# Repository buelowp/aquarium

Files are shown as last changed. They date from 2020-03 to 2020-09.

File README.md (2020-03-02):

# Aquarium Sensor Monitor

I have had aquariums for a while, so I decided one day to add some specific sensors to help me keep track of the
health of the aquarium over time. Atlas makes some really nice, if not expensive, water sensors than can be used in both
fresh and saltwater tanks. For my freshwater tank, I plan to add dissolved oxygen and a pH sensor to help me keep track
of what's going on during the day. I also plan to add a temperature monitor and have added support for keeping track 
of the flow rate for the pump and a water level sensor to make sure I have water in there. The goal is to give me 
some insight into tank health as time goes by, and provide me with rapid warning if something critically bad happens.

To do this, I've created a board to hold a Rasperry PI Zero W, along with space to add the Atlas sensors and a ADC to 
help me keep track of water level. It is a somewhat complicated 4 layer PCB that includes the PI, three Atlas sensor installations, two temp probes, a couple of random GPIO (to control whatever), and an 8 channel ADC, though currently 
I only use 1. They don't make a through hole 1 channel ADC that I can find.

This is also designed to work with my Android Things Aquarium display, which will give me some visual feedback when 
wanted about the state of the tank. It will also give me the ability to track cleanings, filter changes, and a list 
of other things that should be tracked over time to avoid letting them go too long.

## Installation

You need a PI zero, with build-essentials and cmake. You compile it doing the following

```
mkdir build
cd build
cmake ..
make
cp app/aquarium /usr/bin
```

You must copy the aquarium.config file to /root/.config, as this app MUST run as root. It's easiest if you start 
it from rc.local as the last item in the list. It has a function to wait on the network, so that shouldn't be too 
big a problem. If the MQTT server doesn't come up in 5 minutes, it will fail. The whole point of this is MQTT 
access to data. It also can talk to AdafruitIO, but doesn't block waiting for that. If that doesn't connect, then 
you can't talk to AdafruitIO.

I won't got into detail about how to build out the hardware right now.

## Configuration

I will describe how to populate the config file here soon.

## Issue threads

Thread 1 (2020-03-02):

Create an error if a device suddenly goes away

buelowp, 2020-03-02:
This app should notice if a device stops reporting and flag that as an error.

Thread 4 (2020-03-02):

convert MQTT to Paho

buelowp, 2020-03-02:
The current mosquitto lib has been deprecated and may not work forever. Switch to Paho C++ for the MQTT implementation.

buelowp, 2020-03-12:
Merged phao port, got it working.

Closed 2020-03-12.

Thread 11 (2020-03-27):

Temp probe names are broken

buelowp, 2020-03-27:
Names assigned to temp probes are not working correctly again. Need to fix this.

buelowp, 2020-03-27:
Merged

Closed 2020-03-27.

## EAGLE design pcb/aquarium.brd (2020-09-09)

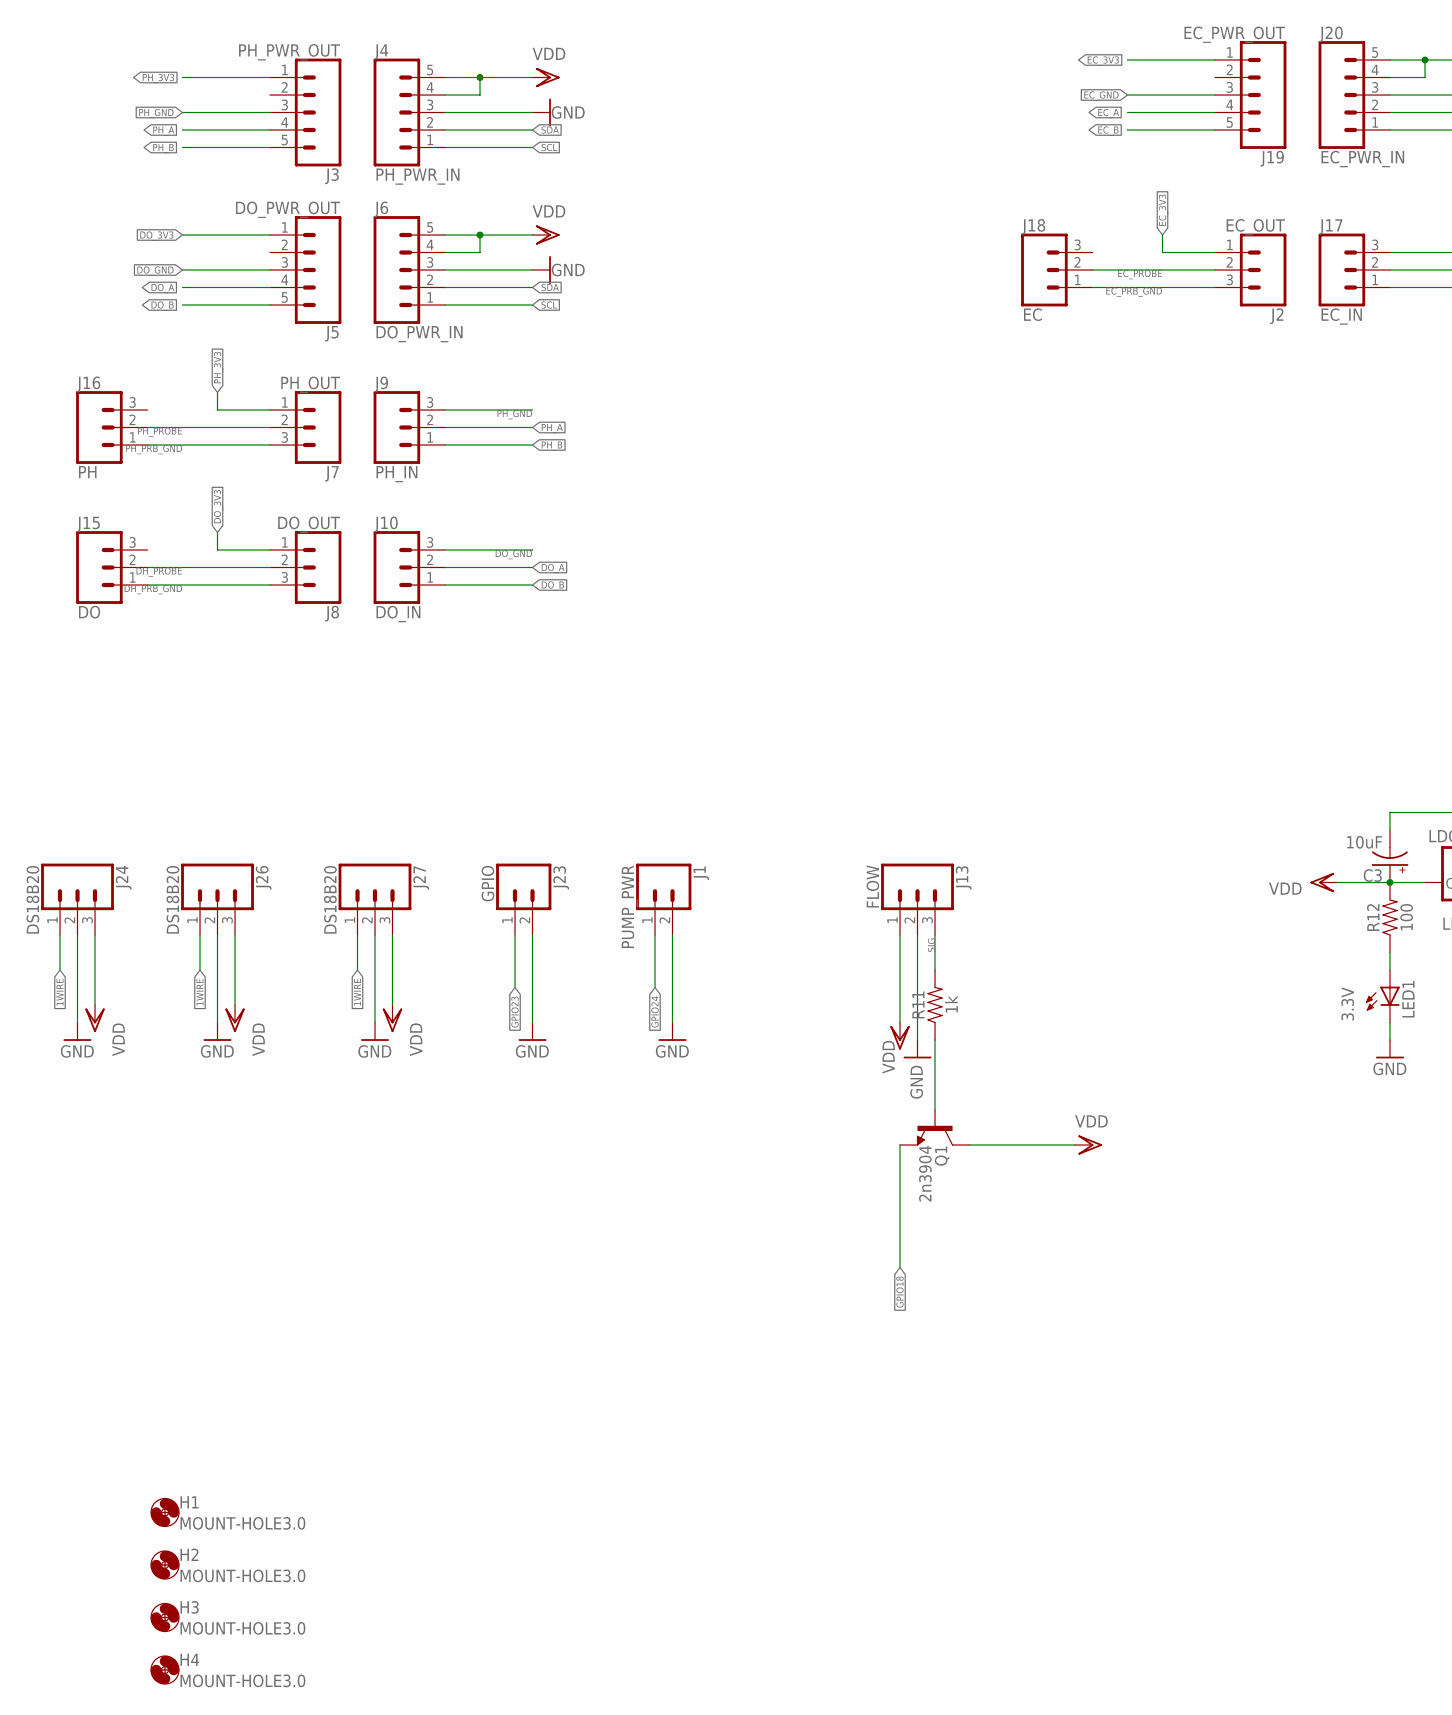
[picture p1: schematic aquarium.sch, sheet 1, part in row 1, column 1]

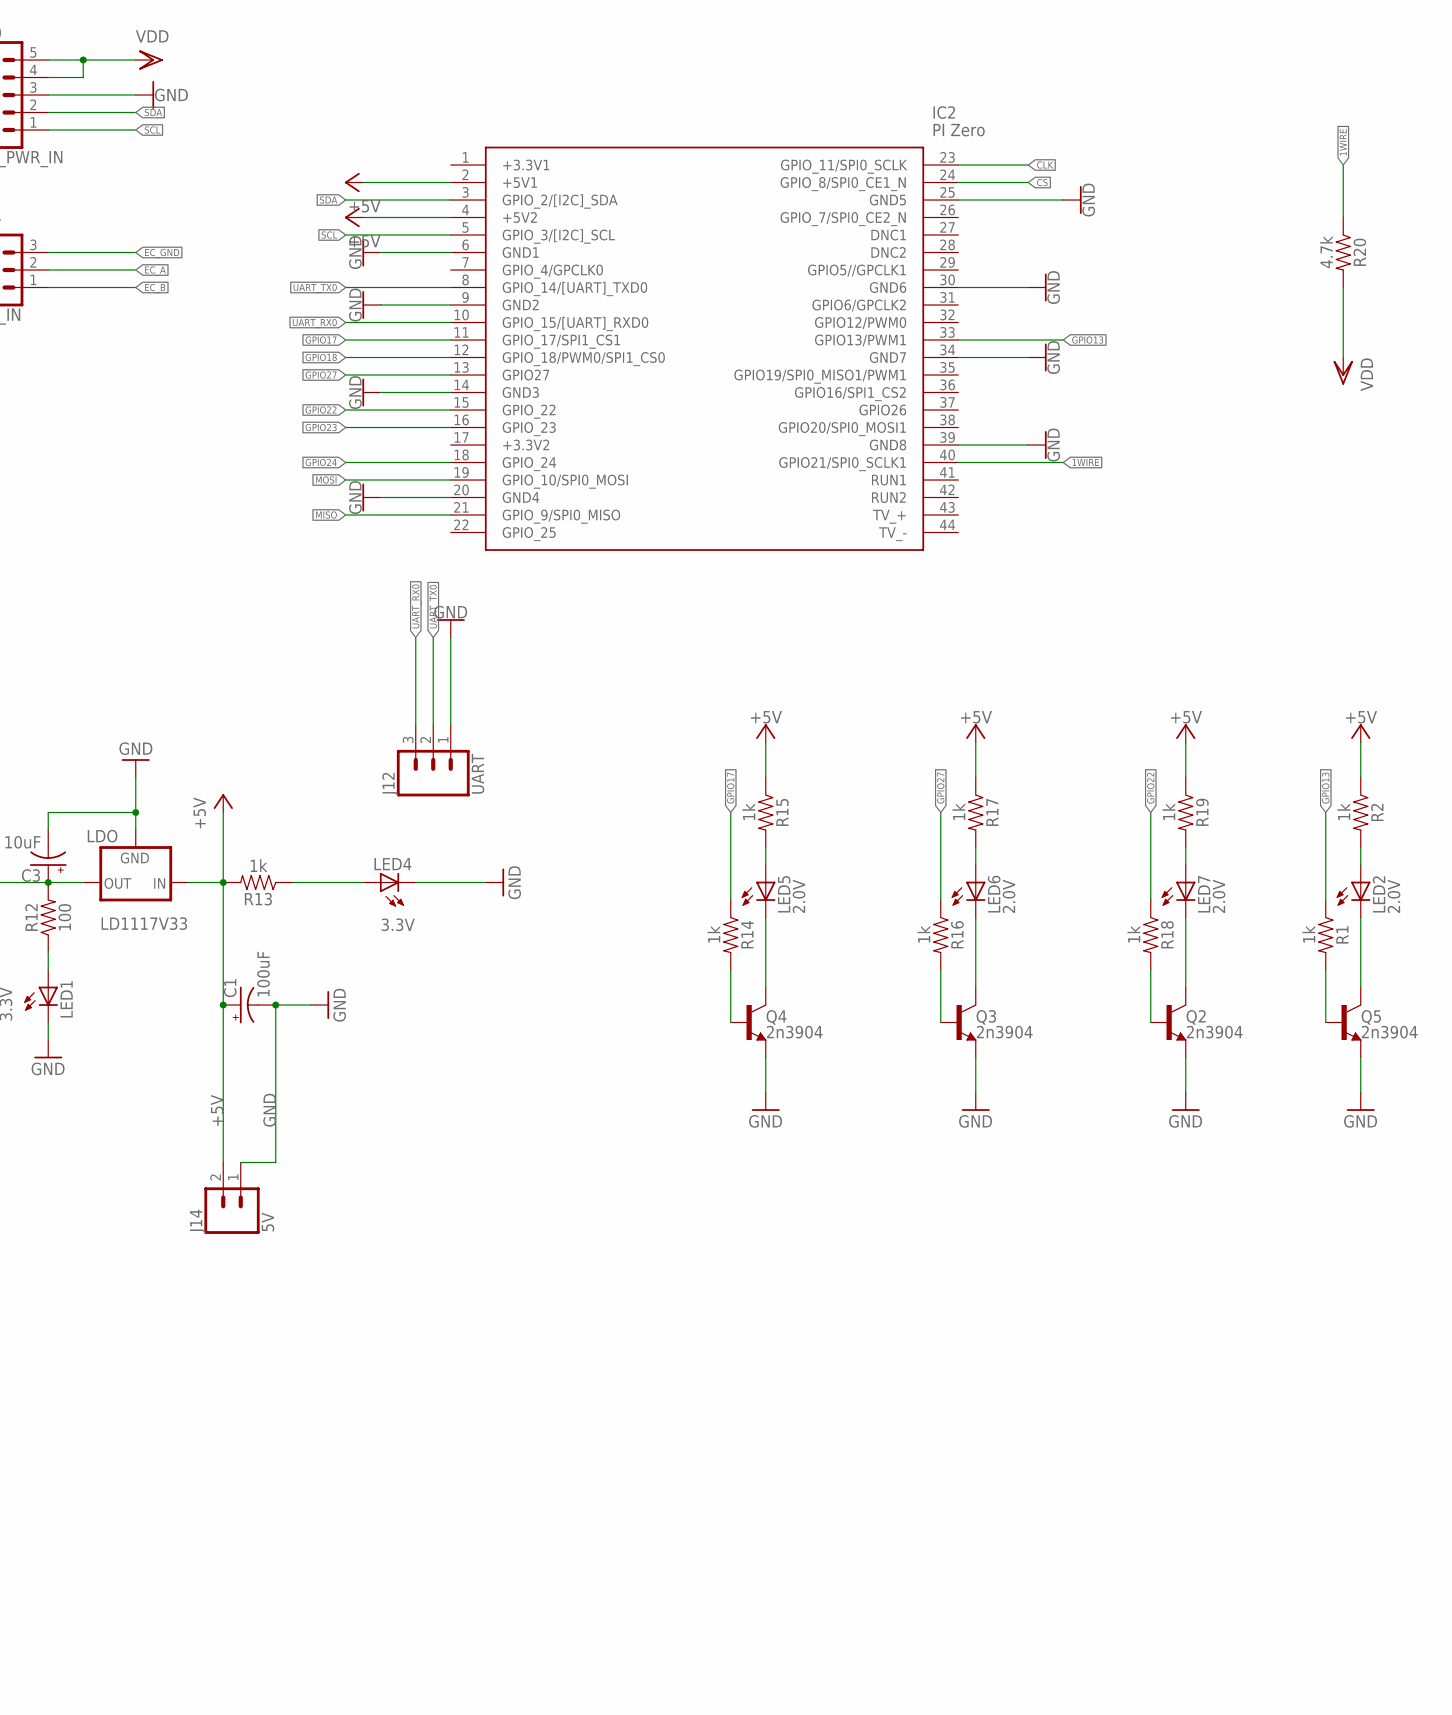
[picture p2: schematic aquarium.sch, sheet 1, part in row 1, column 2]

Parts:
C1: 100uF; CPOL-RADIAL-2.5MM-6.5MM
C3: 10uF; CPOL-RADIAL-2.5MM-5MM
H1, H2, H3, H4: MOUNT-HOLE3.0; 3,0
IC2: PI Zero; RASPBERRYPIZEROWV13
J1: PUMP_PWR; 1X02
J2: EC_OUT; 1X03
J3: PH_PWR_OUT; 1X05
J4: PH_PWR_IN; 1X05
J5: DO_PWR_OUT; 1X05
J6: DO_PWR_IN; 1X05
J7: PH_OUT; 1X03
J8: DO_OUT; 1X03
J9: PH_IN; 1X03
J10: DO_IN; 1X03
J12: UART; 1X03
J13: FLOW; 1X03
J14: 5V; 1X02
J15: DO; 1X03
J16: PH; 1X03
J17: EC_IN; 1X03
J18: EC; 1X03
J19: EC_PWR_OUT; 1X05
J20: EC_PWR_IN; 1X05
J23: GPIO; 1X02
J24, J26, J27: DS18B20; 1X03
LDO: LD1117V33; 78XXL
LED1, LED4: 3.3V; LED3MM
LED2, LED5, LED6, LED7: 2.0V; LED3MM
Q1, Q2, Q3, Q4, Q5: 2n3904; TO-92
R1, R2, R11, R13, R14, R15, R16, R17, R18, R19: 1k; AXIAL-0.3
R12: 100; AXIAL-0.3
R20: 4.7k; AXIAL-0.3

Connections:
1WIRE: IC2.40 (GPIO21/SPI0_SCLK1), J24.1, J26.1, J27.1, R20.P$1 (1)
+5V: C1.1 (+), IC2.2 (+5V1), IC2.4 (+5V2), J14.2, LDO.OUT (IN), R2.P$1 (1), R13.P$2 (2), R15.P$1 (1), R17.P$1 (1), R19.P$1 (1); also elsewhere on the board
CLK: IC2.23 (GPIO_11/SPI0_SCLK); also elsewhere on the board
CS: IC2.24 (GPIO_8/SPI0_CE1_N); also elsewhere on the board
DH_PRB_GND: J8.3, J15.1
DH_PROBE: J8.2, J15.2
DO_3V3: J5.1, J8.1
DO_A: J5.4, J10.2
DO_B: J5.5, J10.1
DO_GND: J5.3, J10.3
EC_3V3: J2.1, J19.1
EC_A: J17.2, J19.4
EC_B: J17.1, J19.5
EC_GND: J17.3, J19.3
EC_PRB_GND: J2.3, J18.1
EC_PROBE: J2.2, J18.2
GND: C1.2 (-), C3.2 (-), IC2.6 (GND1), IC2.9 (GND2), IC2.14 (GND3), IC2.20 (GND4), IC2.25 (GND5), IC2.30 (GND6), IC2.34 (GND7), IC2.39 (GND8), J1.2, J4.3, J6.3, J12.1, J13.2, J14.1, J20.3, J23.2, J24.2, J26.2, J27.2, LDO.IN (GND), LED1.K (C), LED4.K (C), Q2.1 (E), Q3.1 (E), Q4.1 (E), Q5.1 (E); also elsewhere on the board
GPIO13: IC2.33 (GPIO13/PWM1), R1.P$1 (1)
GPIO17: IC2.11 (GPIO_17/SPI1_CS1), R14.P$1 (1)
GPIO18: IC2.12 (GPIO_18/PWM0/SPI1_CS0), Q1.1 (E)
GPIO22: IC2.15 (GPIO_22), R18.P$1 (1)
GPIO23: IC2.16 (GPIO_23), J23.1
GPIO24: IC2.18 (GPIO_24), J1.1
GPIO27: IC2.13 (GPIO27), R16.P$1 (1)
MISO: IC2.21 (GPIO_9/SPI0_MISO); also elsewhere on the board
MOSI: IC2.19 (GPIO_10/SPI0_MOSI); also elsewhere on the board
unnamed: LED1.A, R12.P$1 (1)
unnamed: Q1.2 (B), R11.P$1 (1)
unnamed: Q4.2 (B), R14.P$2 (2)
unnamed: LED4.A, R13.P$1 (1)
unnamed: Q3.2 (B), R16.P$2 (2)
unnamed: LED5.A, R15.P$2 (2)
unnamed: Q2.2 (B), R18.P$2 (2)
unnamed: LED5.K (C), Q4.3 (C)
unnamed: LED6.A, R17.P$2 (2)
unnamed: LED6.K (C), Q3.3 (C)
unnamed: LED7.A, R19.P$2 (2)
unnamed: LED7.K (C), Q2.3 (C)
unnamed: Q5.2 (B), R1.P$2 (2)
unnamed: LED2.A, R2.P$2 (2)
unnamed: LED2.K (C), Q5.3 (C)
PH_3V3: J3.1, J7.1
PH_A: J3.4, J9.2
PH_B: J3.5, J9.1
PH_GND: J3.3, J9.3
PH_PRB_GND: J7.3, J16.1
PH_PROBE: J7.2, J16.2
SCL: IC2.5 (GPIO_3/[I2C]_SCL), J4.1, J6.1, J20.1; also elsewhere on the board
SDA: IC2.3 (GPIO_2/[I2C]_SDA), J4.2, J6.2, J20.2; also elsewhere on the board
SIG: J13.3, R11.P$2 (2)
UART_RX0: IC2.10 (GPIO_15/[UART]_RXD0), J12.3
UART_TX0: IC2.8 (GPIO_14/[UART]_TXD0), J12.2
VDD: C3.1 (+), J4.4, J4.5, J6.4, J6.5, J13.1, J20.4, J20.5, J24.3, J26.3, J27.3, LDO.GND (OUT), Q1.3 (C), R12.P$2 (2), R20.P$2 (2); also elsewhere on the board

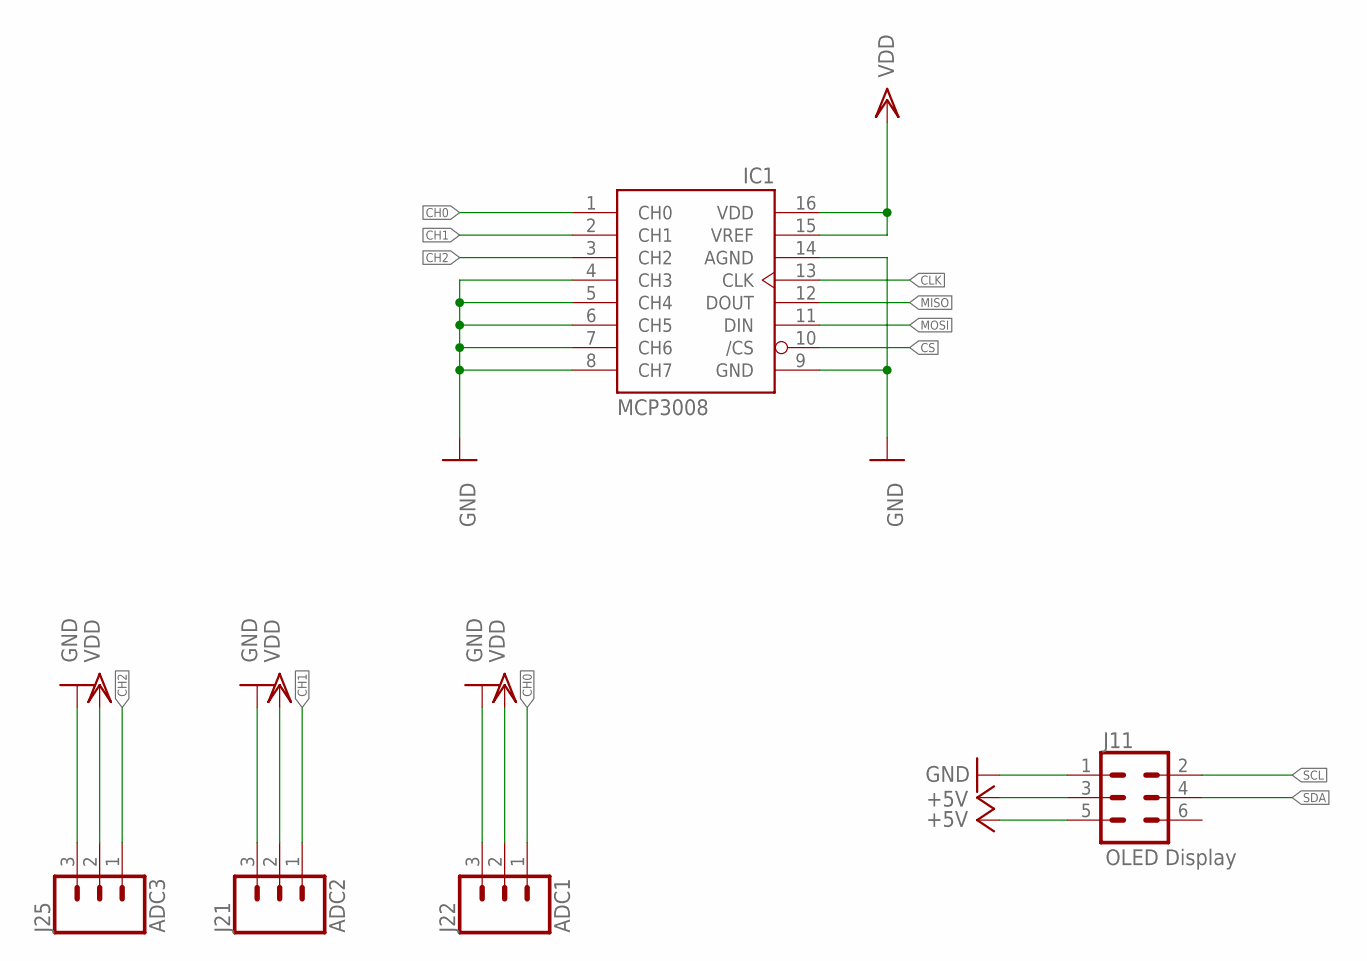
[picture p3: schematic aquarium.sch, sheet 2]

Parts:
IC1: MCP3008; DIL16
J11: OLED Display; 2X3
J21: ADC2; 1X03
J22: ADC1; 1X03
J25: ADC3; 1X03

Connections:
+5V: J11.3, J11.5; also elsewhere on the board
CH0: IC1.1 (CH0), J22.1
CH1: IC1.2 (CH1), J21.1
CH2: IC1.3 (CH2), J25.1
CLK: IC1.13 (CLK); also elsewhere on the board
CS: IC1.10 (/CS); also elsewhere on the board
GND: IC1.4 (CH3), IC1.5 (CH4), IC1.6 (CH5), IC1.7 (CH6), IC1.8 (CH7), IC1.9 (GND), IC1.14 (AGND), J11.1, J21.3, J22.3, J25.3; also elsewhere on the board
MISO: IC1.12 (DOUT); also elsewhere on the board
MOSI: IC1.11 (DIN); also elsewhere on the board
SCL: J11.2; also elsewhere on the board
SDA: J11.4; also elsewhere on the board
VDD: IC1.15 (VREF), IC1.16 (VDD), J21.2, J22.2, J25.2; also elsewhere on the board

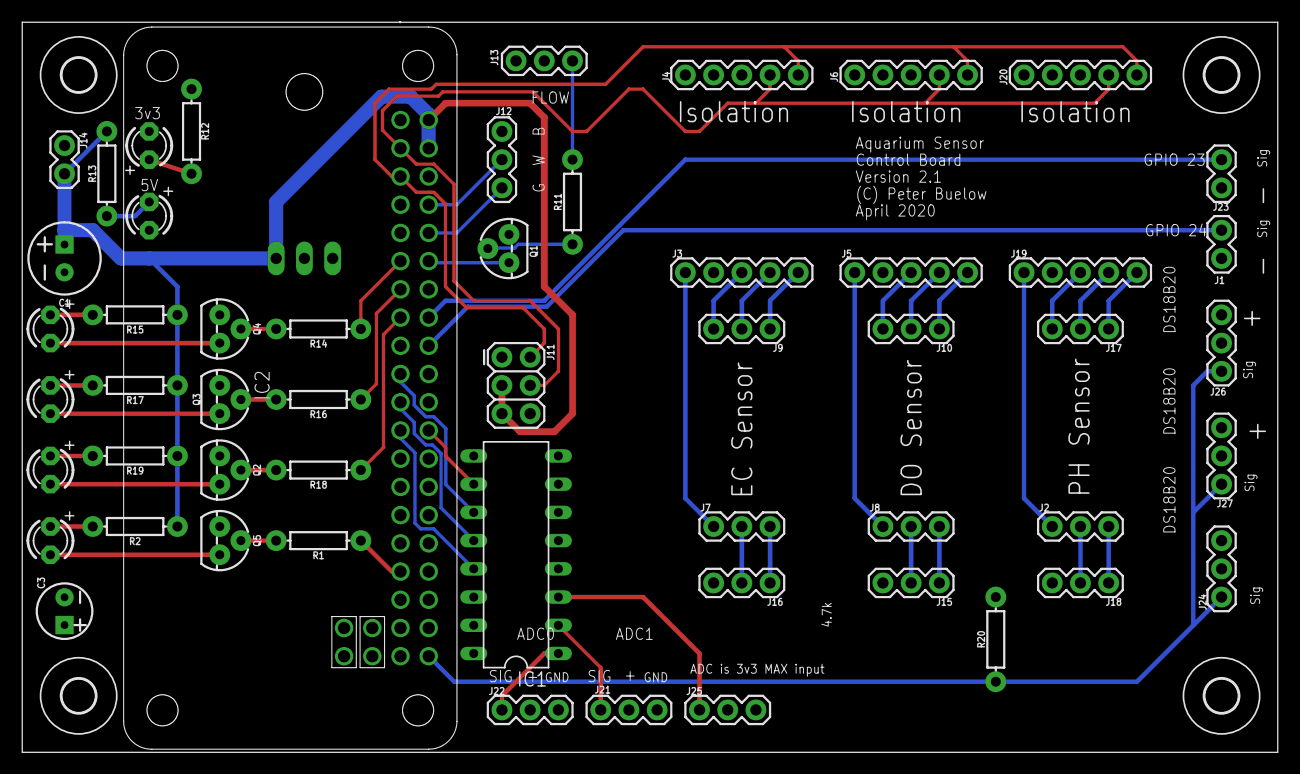
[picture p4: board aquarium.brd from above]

Board: 4 copper layers, 113.0 x 65.7 mm, 59 parts (1 on the bottom side), 56 nets.

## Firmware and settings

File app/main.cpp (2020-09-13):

/*
 * Copyright (c) 2019 Peter Buelow <goballstate at gmail dot com>
 * 
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
 * THE SOFTWARE IS PROVIDED "AS IS", WITHOUT WARRANTY OF ANY KIND,
 * EXPRESS OR IMPLIED, INCLUDING BUT NOT LIMITED TO THE WARRANTIES
 * OF MERCHANTABILITY, FITNESS FOR A PARTICULAR PURPOSE AND
 * NONINFRINGEMENT. IN NO EVENT SHALL THE AUTHORS OR COPYRIGHT
 * HOLDERS BE LIABLE FOR ANY CLAIM, DAMAGES OR OTHER LIABILITY,
 * WHETHER IN AN ACTION OF CONTRACT, TORT OR OTHERWISE, ARISING
 * FROM, OUT OF OR IN CONNECTION WITH THE SOFTWARE OR THE USE OR
 * OTHER DEALINGS IN THE SOFTWARE.
 */

#include <iostream>
#include <fstream>
#include <thread>
#include <chrono>
#include <cstring>
#include <iomanip>
#include <ctime>
#include <sstream>
#include <mutex>
#include <condition_variable>

#include <wiringPi.h>
#include <syslog.h>
#include <signal.h>
#include <libgen.h>
#include <errno.h>
#include <nlohmann/json.hpp>

#include "potentialhydrogen.h"
#include "dissolvedoxygen.h"
#include "itimer.h"
#include "temperature.h"
#include "mcp3008.h"
#include "configuration.h"
#include "errorhandler.h"
#include "fatal.h"
#include "critical.h"
#include "warning.h"
#include "localmqttcallback.h"

#define ONE_SECOND          1000
#define TEN_SECONDS         (ONE_SECOND * 10)
#define ONE_MINUTE          (ONE_SECOND * 60)
#define FIVE_MINUTES        (ONE_MINUTE * 5)
#define FIFTEEN_MINUTES     (ONE_MINUTE * 15)
#define ONE_HOUR            (ONE_MINUTE * 60)

#define AIO_FLOWRATE_FEED   "pbuelow/feeds/aquarium.flowrate"
#define AIO_OXYGEN_FEED     "pbuelow/feeds/aquarium.oxygen"
#define AIO_PH_FEED         "pbuelow/feeds/aquarium.ph"
#define AIO_TEMP_FEED       "pbuelow/feeds/aquarium.Temperature"
#define AIO_LEVEL_FEED      "pbuelow/feeds/aquarium.waterlevel"

ErrorHandler g_errors;
std::mutex g_mqttMutex;
std::condition_variable g_mqttCV;
std::mutex g_decodeMutex;
std::mutex g_statusMutex;
bool g_finished;
bool g_stopRapidFireWaterLevel;
bool g_exitImmediately;
int g_gpioPortOneState;
int g_gpioPortTwoState;

void gpioPortOneISR()
{
    static int lastErrorHandle = 0;
    g_gpioPortOneState = digitalRead(Configuration::instance()->m_gpioPortOne);
    if (g_gpioPortOneState == 1) {
        lastErrorHandle = g_errors.warning(std::string("Left overflow is reporting high water"), Configuration::instance()->m_mqtt, 0);
    }
    else {
        if (lastErrorHandle > 0) {
            g_errors.clearWarning(lastErrorHandle);
            lastErrorHandle = 0;
        }
    }
}

void gpioPortTwoISR()
{
    static int lastErrorHandle = 0;
    g_gpioPortTwoState = digitalRead(Configuration::instance()->m_gpioPortTwo);
    if (g_gpioPortTwoState == 1) {
        lastErrorHandle = g_errors.warning(std::string("Right overflow is reporting high water"), Configuration::instance()->m_mqtt, 0);
    }
    else {
        if (lastErrorHandle > 0) {
            g_errors.clearWarning(lastErrorHandle);
            lastErrorHandle = 0;
        }
    }
}

void eternalBlinkAndDie(int pin, int millihz)
{
    int state = 0;
    digitalWrite(pin, state);
    while (1) {
        std::this_thread::sleep_for(std::chrono::milliseconds(millihz));
        state ^= 1UL << 0;
        digitalWrite(pin, state); 
    }
}

void initializeLeds()
{
    pinMode(Configuration::instance()->m_greenLed, OUTPUT);
    pinMode(Configuration::instance()->m_yellowLed, OUTPUT);
    pinMode(Configuration::instance()->m_redLed, OUTPUT);
    
    digitalWrite(Configuration::instance()->m_greenLed, HIGH);
    digitalWrite(Configuration::instance()->m_yellowLed, LOW);
    digitalWrite(Configuration::instance()->m_redLed, LOW);

    std::this_thread::sleep_for(std::chrono::milliseconds(500));
    digitalWrite(Configuration::instance()->m_greenLed, LOW);
    digitalWrite(Configuration::instance()->m_yellowLed, HIGH);
    std::this_thread::sleep_for(std::chrono::milliseconds(500));
    digitalWrite(Configuration::instance()->m_yellowLed, LOW);
    digitalWrite(Configuration::instance()->m_redLed, HIGH);
    std::this_thread::sleep_for(std::chrono::milliseconds(500));
    digitalWrite(Configuration::instance()->m_redLed, LOW);
    digitalWrite(Configuration::instance()->m_greenLed, HIGH);
}

bool cisCompare(const std::string & str1, const std::string &str2)
{
    return ((str1.size() == str2.size()) && std::equal(str1.begin(), str1.end(), str2.begin(), 
            [](const char c1, const char c2)
            { return (c1 == c2 || std::toupper(c1) == std::toupper(c2)); }
            ));
}

void decodeStatusResponse(std::string which, std::string &response)
{
    static int lastWarningHandle = 0;
    static int lastErrorHandle = 0;
    nlohmann::json j;
    std::string::size_type pos = response.find_last_of(",");
    double voltage;
    
    g_statusMutex.lock();
    if (pos != std::string::npos) {
        if (lastErrorHandle > 0) {
            g_errors.clearCritical(lastErrorHandle);
            lastErrorHandle = 0;
        }
        voltage = std::stod(response.substr(pos + 1));
        if (voltage > 3) {
            if (lastWarningHandle > 0) {
                g_errors.clearWarning(lastWarningHandle);
                lastWarningHandle = 0;
            }
        }
        else {
            std::cerr << __PRETTY_FUNCTION__ << ":" << __LINE__ << ": probe is reporting an unusual voltage (" << voltage << "), it may not be operating correctly." << std::endl;
            lastWarningHandle = g_errors.warning(std::string(which + " probe is reporting undervoltage"), Configuration::instance()->m_mqtt, 0);
        }
        if (which == "pH") {
            j["aquarium"]["device"]["ph"]["voltage"] = response.substr(pos + 1);
            Configuration::instance()->m_phVoltage = response.substr(pos + 1);
        }
        else if (which == "DO") {
            j["aquarium"]["device"]["dissolvedoxygen"]["version"] = response.substr(pos + 1);
            Configuration::instance()->m_o2Voltage = response.substr(pos + 1);
        }
        if (Configuration::instance()->m_mqttConnected)
            Configuration::instance()->m_mqtt->publish("aquarium2/device", j.dump());
        
        std::cout << __PRETTY_FUNCTION__ << ":" << __LINE__ << ": " << which << ": probe is operating normally, reporting voltage " << voltage << std::endl;
    }
    else {
        std::cout << __PRETTY_FUNCTION__ << ":" << __LINE__ << ": probe status cannot be decoded" << std::endl;
        lastErrorHandle = g_errors.critical(std::string(which + " probe is returning garbage"), Configuration::instance()->m_mqtt, 0);
    }
    g_statusMutex.unlock();
}

void decodeInfoResponse(std::string which, std::string &response)
{
    static int lastErrorHandle = 0;
    nlohmann::json j;
    std::string::size_type pos = response.find_last_of(",");
    
    if (pos != std::string::npos) {
        if (lastErrorHandle > 0) {
            g_errors.clearCritical(lastErrorHandle);
            lastErrorHandle = 0;
        }
        if (which == "pH") {
            j["aquarium"]["device"]["ph"]["version"] = response.substr(pos + 1);
            Configuration::instance()->m_phVersion = response.substr(pos + 1);
        }
        else if (which == "DO") {
            j["aquarium"]["device"]["dissolvedoxygen"]["version"] = response.substr(pos + 1);
            Configuration::instance()->m_o2Version = response.substr(pos + 1);
        }

        if (Configuration::instance()->m_mqttConnected)
            Configuration::instance()->m_mqtt->publish("aquarium2/device", j.dump());
        
        std::cout << __PRETTY_FUNCTION__ << ":" << __LINE__ << ": " << which << ": version " << response.substr(pos + 1) << std::endl;        
    }
    else {
        std::cerr << __PRETTY_FUNCTION__ << ":" << __LINE__ << ": probe info response cannot be decoded" << std::endl;
        lastErrorHandle = g_errors.critical(std::string(which + " probe is returning garbage"), Configuration::instance()->m_mqtt, 0);
    }
}

void decodeTempCompensation(std::string which, std::string &response)
{
    static int lastErrorHandle = 0;
    nlohmann::json j;

    std::string::size_type pos = response.find_last_of(",");
    if (pos != std::string::npos) {
        if (which == "pH") {
            j["aquarium"]["device"]["ph"]["tempcompensation"] = response.substr(pos + 1);
            Configuration::instance()->m_o2TempComp = response.substr(pos + 1);
        }
        else if (which == "DO") {
            j["aquarium"]["device"]["dissolvedoxygen"]["tempcompensation"] = response.substr(pos + 1);
            Configuration::instance()->m_o2TempComp = response.substr(pos + 1);
        }
        Configuration::instance()->m_mqtt->publish("aquarium2/device", j.dump());
        std::cout << __PRETTY_FUNCTION__ << ":" << __LINE__ << ": " << which << ": probe has a temp compensation value of " << response.substr(pos + 1) << "C" << std::endl;
    }
    else {
        std::cerr << __PRETTY_FUNCTION__ << ":" << __LINE__ << ": probe temp compensation response cannot be decoded" << std::endl;
        lastErrorHandle = g_errors.critical(std::string(which + " probe is returning garbage"), Configuration::instance()->m_mqtt, 0);
    }
}

void phCallback(int cmd, std::string response)
{
    switch (cmd) {
        case AtlasScientificI2C::INFO:
            syslog(LOG_NOTICE, "got pH probe info event: %s\n", response.c_str());
            decodeInfoResponse("pH", response);
            break;
        case AtlasScientificI2C::STATUS:
            syslog(LOG_NOTICE, "got pH probe status event: %s\n", response.c_str());
            decodeStatusResponse("pH", response);
            break;
        case AtlasScientificI2C::CALIBRATE:
            if (response.find(",0") != std::string::npos)
                std::cout << __PRETTY_FUNCTION__ << ":" << __LINE__ << ": pH: probe reports no calibration data..." << std::endl;
            break;
        case AtlasScientificI2C::SETTEMPCOMPREAD:
        case AtlasScientificI2C::GETTEMPCOMP:
            decodeTempCompensation("pH", response);
            break;
        default:
            break;
    }
}

void doCallback(int cmd, std::string response)
{
    switch (cmd) {
        case AtlasScientificI2C::INFO:
            syslog(LOG_NOTICE, "got DO probe info event: %s\n", response.c_str());
            decodeInfoResponse("DO", response);
            break;
        case AtlasScientificI2C::STATUS:
            syslog(LOG_NOTICE, "got DO probe status event: %s\n", response.c_str());
            decodeStatusResponse("DO", response);
            break;
        case AtlasScientificI2C::CALIBRATE:
            if (response.find(",0") != std::string::npos)
                std::cout << __PRETTY_FUNCTION__ << ":" << __LINE__ << ": DO: probe reports no calibration data..." << std::endl;
            break;
        case AtlasScientificI2C::SETTEMPCOMPREAD:
        case AtlasScientificI2C::GETTEMPCOMP:
            decodeTempCompensation("DO", response);
            break;
        default:
            break;
    }
}

void sendLocalResultData()
{
    nlohmann::json j;
    std::time_t t = std::time(nullptr);
    char timebuff[100];

    memset(timebuff, '\0', 100);
    std::strftime(timebuff, 100, "%c", std::localtime(&t));

    j["aquarium"]["time"]["epoch"] = t;
    j["aquarium"]["time"]["local"] = timebuff;
    j["aquarium"]["waterlevel"] = Configuration::instance()->m_adc->reading(Configuration::instance()->m_adcWaterLevelIndex);
    
    if (Configuration::instance()->m_temp->enabled()) {
        std::map<std::string, std::string> devices = Configuration::instance()->m_temp->devices();
        auto it = devices.begin();
        while (it != devices.end()) {
            double c = Configuration::instance()->m_temp->getTemperatureByDevice(it->first);
            j["aquarium"]["temperature"][it->second]["celsius"] = c;
            j["aquarium"]["temperature"][it->second]["farenheit"] = Configuration::instance()->m_temp->convertToFarenheit(c);
            it++;
        }
    }

    j["aquarium"]["ph"] = Configuration::instance()->m_ph->getPH();
    j["aquarium"]["oxygen"] = Configuration::instance()->m_oxygen->getDO();
    if (Configuration::instance()->m_gpioPortOne != 0) {
        j["aquarium"]["gpio"]["1"] = g_gpioPortOneState;
    }
    
    if (Configuration::instance()->m_gpioPortTwo != 0) {
        j["aquarium"]["gpio"]["2"] = g_gpioPortTwoState;
    }
    
    if (Configuration::instance()->m_mqttConnected)
        Configuration::instance()->m_mqtt->publish("aquarium2/data", j.dump());
}

void sendAIOResultData()
{
    if (Configuration::instance()->m_aioConnected) {
        nlohmann::json wlj;
        nlohmann::json o2j;
        nlohmann::json phj;
        nlohmann::json tempj;
        
        wlj["value"] = Configuration::instance()->m_adc->reading(Configuration::instance()->m_adcWaterLevelIndex);
        std::cout << __PRETTY_FUNCTION__ << ":" << __LINE__ <<  ": pbuelow/feeds/aquarium.waterlevel: " << wlj.dump() << std::endl;
        mqtt::message_ptr wl = mqtt::make_message("pbuelow/feeds/aquarium.waterlevel", wlj.dump());
        Configuration::instance()->m_aio->publish(wl);
        
        phj["value"] = Configuration::instance()->m_ph->getPH();
        mqtt::message_ptr ph = mqtt::make_message("pbuelow/feeds/aquarium.ph", phj.dump());
        Configuration::instance()->m_aio->publish(ph);
        
        o2j["value"] = Configuration::instance()->m_oxygen->getDO();
        mqtt::message_ptr oxy = mqtt::make_message("pbuelow/feeds/aquarium.oxygen", o2j.dump());
        Configuration::instance()->m_aio->publish(oxy);

        if (Configuration::instance()->m_temp->enabled()) {
            std::map<std::string, std::string> devices = Configuration::instance()->m_temp->devices();
            auto it = devices.begin();
            if (it != devices.end()) {
                double c = Configuration::instance()->m_temp->getTemperatureByDevice(it->first);
                tempj["value"] = Configuration::instance()->m_temp->convertToFarenheit(c);
                mqtt::message_ptr temp = mqtt::make_message("pbuelow/feeds/aquarium.temperature", tempj.dump());
                Configuration::instance()->m_aio->publish(temp);
            }
        }
    }
}

void setTempCompensation()
{
    std::map<std::string, std::string> devices = Configuration::instance()->m_temp->devices();
    double c;

    auto it = devices.begin();

    if (it != devices.end()) {
        c = Configuration::instance()->m_temp->getTemperatureByDevice(it->first);

        std::cout << __PRETTY_FUNCTION__ << ":" << __LINE__ << ": Setting temp compensation value for probes to " << c << std::endl;
        if (c != 0) {
            Configuration::instance()->m_ph->setTempCompensation(c);
            Configuration::instance()->m_oxygen->setTempCompensation(c);
            Configuration::instance()->m_ph->getTempCompensation();
            Configuration::instance()->m_oxygen->getTempCompensation();
        }
        it++;
    }
}

void sendTempProbeIdentification()
{
    std::map<std::string, std::string> devices = Configuration::instance()->m_temp->devices();
    nlohmann::json j;
    int index = 1;

    auto it = devices.begin();
    
    while (it != devices.end()) {
        j["aquarium"]["device"]["ds18b20"][index]["name"] = it->second;
        j["aquarium"]["device"]["ds18b20"][index]["device"] = it->first;
        it++;
        index++;
    }
    if (Configuration::instance()->m_mqtt->is_connected())
        Configuration::instance()->m_mqtt->publish("aquarium2/devices", j.dump());
}

/*
 * {"serial":"name"}
 */
void nameTempProbe(std::string json)
{
    std::map<std::string, std::string> entry;
    auto j = nlohmann::json::parse(json);

    if (!j.is_null()) {
        for (auto& el : j.items()) {
            std::cout << __PRETTY_FUNCTION__ << ":" << __LINE__ <<  ": " << el.key() << ":" << el.value() << std::endl;
            entry[el.key()] = el.value();
        }
    }
    else {
        std::cout << __PRETTY_FUNCTION__ << ":" << __LINE__ <<  ": j is null: " << json << std::endl;
    }
    
    if (entry.size())
        Configuration::instance()->updateArray(std::string("ds18b20"), entry);
}

void rapidFireWaterLevelMessaging(void *t)
{
    nlohmann::json j;
    ITimer *timer = static_cast<ITimer*>(t);
    
    if (g_stopRapidFireWaterLevel) {
        timer->stop();
        std::this_thread::sleep_for(std::chrono::seconds(1));
        delete timer;
        return;
    }
    j["aquarium"]["waterlevel"] = Configuration::instance()->m_adc->reading(Configuration::instance()->m_adcWaterLevelIndex);

    if (Configuration::instance()->m_mqtt->is_connected())
        Configuration::instance()->m_mqtt->publish("aquarium2/waterlevel/value", j.dump());
}

void mqttIncomingMessage(std::string topic, std::string message)
{
    std::cout << __PRETTY_FUNCTION__ << ":" << __LINE__ <<  ": Handling topic " << topic << std::endl;
    if (topic == "aquarium2/set/ds18b20") {
        nameTempProbe(message);
    }
    if (topic == "aquarium2/waterlevel/rapidfire/start") {
        ITimer *t = new ITimer();
        t->setInterval(rapidFireWaterLevelMessaging, 500);
        g_stopRapidFireWaterLevel = false;
    }
    if (topic == "aquarium2/waterlevel/rapidfire/stop") {
        g_stopRapidFireWaterLevel = true;        
    }
}

void mqttConnectionLost(const std::string &cause)
{
    std::cout << __PRETTY_FUNCTION__ << ":" << __LINE__ << "MQTT disconnected: " << cause << std::endl;
    Configuration::instance()->m_mqttConnected = false;
    g_errors.warning("MQTT connection lost", Configuration::instance()->m_mqtt, 0, ErrorHandler::StaticErrorHandles::MqttConnectionLost);
}

void mqttConnected()
{
    std::cout << __PRETTY_FUNCTION__ << ":" << __LINE__ << ": MQTT connected!" << std::endl;
    Configuration::instance()->m_mqttConnected = true;

    Configuration::instance()->m_mqtt->subscribe("aquarium2/set/#", 1);
    Configuration::instance()->m_mqtt->subscribe("aquarium2/waterlevel/rapidfire/#", 1);

    g_finished = true;
    g_mqttCV.notify_all();
    g_errors.clearWarning(ErrorHandler::StaticErrorHandles::MqttConnectionLost);
}

void aioIncomingMessage(std::string topic, std::string message)
{
    std::cout << __FUNCTION__ << ": Odd, we shouldn't get messages from AIO" << std::endl;
}

void aioConnected()
{
    std::cout << __PRETTY_FUNCTION__ << ":" << __LINE__ << "AIO connected!" << std::endl;
    Configuration::instance()->m_aioConnected = true;
}

void aioConnectionLost(const std::string &cause)
{
    std::cout << __PRETTY_FUNCTION__ << ":" << __LINE__  << ": AIO disconnected: " << cause << std::endl;
    Configuration::instance()->m_aioEnabled = false;
}
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
int main(int argc, char *argv[])
{
    std::string progname = basename(argv[0]);
    g_finished = false;
    g_exitImmediately = false;
    
    openlog(progname.c_str(), LOG_CONS | LOG_PID | LOG_NDELAY, LOG_LOCAL1);
    
    syslog(LOG_NOTICE, "Application startup");
    
    /** Do our best to clean up and exit if we can **/
    signal(SIGINT, handle_sigint);
    signal(SIGILL, handle_sigint);
    signal(SIGABRT, handle_sigint);
    signal(SIGFPE, handle_sigint);
    
    wiringPiSetupGpio();
    piHiPri(99);
    
    if (!parse_args(argc, argv)) {
        std::cerr << "Error parsing command line, exiting..." << std::endl;
        syslog(LOG_ERR, "Error parsing command line, exiting...");
        exit(-1);
    }
    
    // if this goes badly, just die but leave the error LED blinking at 1 hz
    if (!Configuration::instance()->readConfigFile()) {
        std::cerr << "Unable to read configuration file, exiting..." << std::endl;
        syslog(LOG_ERR, "Unable to read configuration file, exiting...");
        exit(-2);
    }

    initializeLeds();

    std::unique_lock<std::mutex> lk(g_mqttMutex);
    Configuration::instance()->createLocalConnection();
    Configuration::instance()->createAIOConnection();

    g_mqttCV.wait(lk, []{return g_finished;});

    Configuration::instance()->m_mqtt->start_consuming();

    Configuration::instance()->m_oxygen->setCallback(doCallback);
    Configuration::instance()->m_ph->setCallback(phCallback);

    Configuration::instance()->m_oxygen->sendInfoCommand();
    Configuration::instance()->m_oxygen->calibrate(DissolvedOxygen::DO_QUERY, nullptr, 0);
    Configuration::instance()->m_oxygen->getTempCompensation();
    Configuration::instance()->m_oxygen->sendStatusCommand();
    Configuration::instance()->m_oxygen->disableLeds();


    Configuration::instance()->m_ph->sendInfoCommand();
    Configuration::instance()->m_ph->calibrate(PotentialHydrogen::PH_QUERY, nullptr, 0);
    Configuration::instance()->m_ph->getTempCompensation();
    Configuration::instance()->m_ph->sendStatusCommand();
    Configuration::instance()->m_ph->disableLeds();
    
    if (Configuration::instance()->m_gpioPortOne != 0) {
        wiringPiISR(Configuration::instance()->m_gpioPortOne, INT_EDGE_BOTH, gpioPortOneISR);
    }
    
    if (Configuration::instance()->m_gpioPortTwo != 0) {
        wiringPiISR(Configuration::instance()->m_gpioPortTwo, INT_EDGE_BOTH, gpioPortTwoISR);
    }

    sendTempProbeIdentification();
    
    mainloop();
    
    return 0;
}

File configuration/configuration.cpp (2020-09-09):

/*
 * Copyright (c) 2020 Peter Buelow <email>
 * 
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
 * THE SOFTWARE IS PROVIDED "AS IS", WITHOUT WARRANTY OF ANY KIND,
 * EXPRESS OR IMPLIED, INCLUDING BUT NOT LIMITED TO THE WARRANTIES
 * OF MERCHANTABILITY, FITNESS FOR A PARTICULAR PURPOSE AND
 * NONINFRINGEMENT. IN NO EVENT SHALL THE AUTHORS OR COPYRIGHT
 * HOLDERS BE LIABLE FOR ANY CLAIM, DAMAGES OR OTHER LIABILITY,
 * WHETHER IN AN ACTION OF CONTRACT, TORT OR OTHERWISE, ARISING
 * FROM, OUT OF OR IN CONNECTION WITH THE SOFTWARE OR THE USE OR
 * OTHER DEALINGS IN THE SOFTWARE.
 */

#include "configuration.h"

Configuration::Configuration()
{
    m_handle = 1;
    m_newTempDeviceFound = false;
}

Configuration::~Configuration()
{
}

void Configuration::setConfigFile(std::string file)
{
    m_configFile = file;
}

bool Configuration::updateArray(std::string array, std::map<std::string, std::string> &entry)
{
    libconfig::Config config;
    std::map<std::string, std::string> newEntries;
    
    try {
        config.readFile(m_configFile.c_str());
    }
    catch(const libconfig::FileIOException &fioex) {
        std::cerr << __PRETTY_FUNCTION__ << ":" << __LINE__ << "I/O error while reading file." << std::endl;
        return false;
    }
    catch(const libconfig::ParseException &pex) {
        std::cerr << __PRETTY_FUNCTION__ << ":" << __LINE__ << "Parse error at " << pex.getFile() << ":" << pex.getLine() << " - " << pex.getError() << std::endl;
        return false;
    }
    
    libconfig::Setting &root = config.getRoot();
    
    if (!root.exists(array)) {
        std::cerr << __PRETTY_FUNCTION__ << ":" << __LINE__ << ": Array " << array.c_str() << "does not exist, use addArray()"  << std::endl;
        return false;
    }

    try {
        libconfig::Setting &arrayEntry = root[array.c_str()];
        for (const auto& [key, value] : entry) {
            std::cout << __PRETTY_FUNCTION__ << ":" << __LINE__ << ": Searching for " << key << ":" << value << std::endl;
            bool found = false;
            for (int i = 0; i < arrayEntry.getLength(); i++) {
                const libconfig::Setting &device = arrayEntry[i];
                std::string serial;
                std::string name;
                if (!device.lookupValue("device", serial) || !device.lookupValue("name", name)) {
                    std::cerr << __PRETTY_FUNCTION__ << ":" << __LINE__ << ": Unable to find device or name in array..." << std::endl;
                    return false;
                }
                
                if (serial == key) {
                    device["device"] = key;
                    device["name"] = value;
                    found = true;
                }
            }
            if (!found) {
                newEntries[key] = value;
            }
        }
    }
    catch (const libconfig::SettingException &e) {
        std::cerr << __PRETTY_FUNCTION__ << ":" << __LINE__ << ": Unable to add elements to the new array: " << e.what() << std::endl;
        return false;
    }
    
    try {
        config.writeFile(m_configFile.c_str());
        std::cerr << __PRETTY_FUNCTION__ << ":" << __LINE__ << ": Updated configuration successfully written to: " << m_configFile << std::endl;
    }
    catch(const libconfig::FileIOException &fioex) {
        std::cerr << __PRETTY_FUNCTION__ << ":" << __LINE__ << ": I/O error while writing file: " << m_configFile << std::endl;
        return false;
    }
    
    // Must do this last, or we'll read/write the file while another process is reading/writing it
    if (newEntries.size() > 0) {
        addArray(array, newEntries);
    }
    
    return true;
}
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

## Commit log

2019-08-29 Removing boost
    * Added a simple interval timer class
    * Updated i2c code to use new timer
2019-08-30 Fixups
    * Lots of API updates/changes/fixes
    * Fixed scoping of the Atlas parent/child classes
    * Fixed GpioInterrupt API issues and use newest version of GpioInterrupt
    * Got it to compile cleanly
    [atlasscientifici2c.cpp, atlasscientifici2c.h, dissolvedoxygen.cpp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]
2019-09-03 Fixing config file issues
    * Made path fixed for $HOME and ~
    * Added some error output
    * Fixed issue with creating config_t as a pointer
    [main.cpp]
2019-10-03 Fixups
    * Adding some more logical config setup
    * Cleanup logging of config at startup
    * Cleanup config defaults to be less redundant
    * Allow for disabling of MQTT and AIO services
    [main.cpp]
2019-10-04 Lots of work
    * Fixed issues with sensor base class to correctly do what it needs to
    do
    * Testing itimer, no real changes
    * Logging changes across the board
    * Now it can talk to the Atlas Science sensors correctly
    [atlasscientifici2c.cpp, atlasscientifici2c.h, dissolvedoxygen.cpp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]
2019-10-07 Getting closer
    * Fixups for making AS sensors work smarter
    * Added new AS sensor commands for both pH and DO
    * Got temperature via DS18B20 working
    * Lots of code cleanup
    [atlasscientifici2c.cpp, atlasscientifici2c.h, dissolvedoxygen.cpp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]
2019-10-08 Getting temperature working
    * Fixed up JSON for temp MQTT
    * Updated to new interface
    [main.cpp]
2019-11-09 Fixes and updates
    * Added Green and Red LED for notifications
    * Bug fixes
    * Addition of flow sensor handling
    [atlasscientifici2c.h, main.cpp]
2019-11-10 More work to fix issues
    * Updated config file for more options
    * Fixed some issues with program
    * Updated temperature to do the right thing
    * Some debug additions
    [dissolvedoxygen.cpp, main.cpp, potentialhydrogen.cpp]
2019-11-10 Logging changes
    * Changed the JSON for temperature
    * Continue to work on status bug
    * Fixed syslog entries
    [dissolvedoxygen.cpp, main.cpp]
2019-11-11 Fixups
    * Fixing an issue with strings from the AS devices, they needed cleaning
    * Some logging cleanups
    * Added a DO calibration routine, not tested
    * Added JSON handler to avoid doing it manually
    [atlasscientifici2c.cpp, atlasscientifici2c.h, dissolvedoxygen.cpp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]
2019-11-13 Adding PCB files for safe keeping
    [aquarium.brd, aquarium.sch]
2019-11-16 Bumping some things
    * Minor updates to main
    * Fixing PCB and schematic
    [aquarium.brd, aquarium.sch]
2019-11-17 First pass at using state leds
2019-12-27 Checkpoint
    * Adding reading for PH
    * Fixed timeout for reading command
    * Make it possible to get last reading
    [atlasscientifici2c.cpp, main.cpp, potentialhydrogen.cpp]
2019-12-27 Big changes
    * Restructure directories
    * Add a new calibration application
2019-12-27 Checkpoint
    * calibration is starting to work
2019-12-27 More calibration work
    * Couldn't get condition variables to work, switched to raw mutex
    * Some display cleanup
2019-12-28 Fixes
    * Made it mostly work, still needs some testing
    [main.cpp, potentialhydrogen.cpp]
2019-12-28 Lots of fixes
    * Added LED support and fixed a LED enable bug
    * Added a query and clear command to the list of options
    * Fixed a bug which stored the last ph value as an int
    * Added some prints
    [main.cpp, potentialhydrogen.cpp]
2019-12-28 Fix missing usage details
    [main.cpp]
2019-12-29 Some updates
    * Once a minute, just collect all the results and then send it if we need to
    * Get PH data every 10 seconds now
    * Disable some of the other timers until we need them
2019-12-29 Useability updates
    * Fixed printing to be easier to understand
    * Remove timers that are no longer necessary
    * Add a DO value retriever
    * Make the read command time delay configurable
    [atlasscientifici2c.cpp, atlasscientifici2c.h, dissolvedoxygen.cpp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]
2019-12-29 Creating a calibration routine for the dissolved oxygen probe
2019-12-29 Temp compensation additions
    * Fixed the Temperature class to use doubles
    * Added new temp compensation methods
    * Query temp compensation at startup
    * Set the temp compensation at startup and after 15 minutes
    [dissolvedoxygen.cpp, main.cpp, potentialhydrogen.cpp]
2019-12-30 More fixes and work
    * Added a new temp compensation print and decode
    * Allow analog resolution to be set by config
    * If MQTT is enabled, publish the data
    * There is a bug in setWarning Display for the temp function, it will segfault still
    [main.cpp]
2019-12-30 Updating PCB design to latest
    [aquarium.brd, aquarium.sch]
2019-12-31 Fixing issues with setting temperature compensation
    * Changed the callbacks
    * Fixed a bug in DO class
    * Fixed a print bug which made it looks like two pH returns
    [main.cpp, potentialhydrogen.cpp]
2019-12-31 Updates to the PCB
    * Removed the power jack and replaced with a 2 wire solution
    * Routing changes associated with the jack removal
    * Added a new Analog channel to round out 4
    * Moved some of the GPIO pins around
    [aquarium.brd, aquarium.sch]
2019-12-31 Simple fixes
    * Add time to the MQTT JSON payload
    * Make the system calibrate temp compensation once an hour
    [main.cpp]
2020-01-02 Lots of updates
    * Added a new MCP3008 handler, removed the MCP3424 handler
    * Created a new configuration singleton to handle app config data
    * Fixups to cmake files to build
    * Remove all references to the MCP3424
    * Some function reordering
    [main.cpp]
2020-01-02 Add missing files
    [configuration.h]
2020-01-11 Adding better DS18B20 handling
    * Add a new handler class for all DS18B20 devices
    * Fixup the actual device class to be smarter
2020-01-12 Some simple changes before I move to the pi
    [configuration.h]
2020-01-14 Fixing a few things
    * Temperature name is now correct for all cases
    * Print JSON for now
    [main.cpp]
2020-01-14 Fixing some issues
    * Make sure the MQTT client knows it's connected
    * Actually check for connection correctly
    [configuration.cpp, main.cpp]
2020-02-10 Fixups
    * Added DO back in
    * Fixed how we do time strings for JSONwq
    [main.cpp]
2020-02-10 Chaning timer code to try to make it more accurate
2020-02-10 Adding a debug print to make sure it works
2020-02-10 Reverting and fixing a few things
    * Going back to sleep_for
    * Make interval the time value
    * try/catch on the function in the interval timer
2020-02-21 Updating mcp3008 to use wiringPi
2020-02-23 More work towards a real error state handler
    [configuration.h]
2020-02-23 Continuing work on error handling
    * Pry won't compile yet, but continuing on
    [errorhandler.cpp, main.cpp]
2020-02-24 More work on an error management routine
    [errorhandler.cpp]
2020-02-24 Cleanups
    * Fix some issues in the error handler
    * Make timers sleep a little less than total time when north of a minute
    [configuration.h]
2020-02-25 Adding some messaging context so we can store the data
    [configuration.h]
2020-02-25 Making it possible to have many DS18B20 devices
2020-02-25 Cleaning up DS18B20 temp readings
    * Having 2 classes do the same thing was confusing, so I reduced it to 1
    [configuration.h]
2020-02-26 Got it compiliing
    * Fixups to dependencies
    * Moved ErrorHandler class out of configuration to avoid circular dependency
    * Fixed up Temp API usage
    [configuration.h]
2020-02-26 Quick fixup for error handling
    [errorhandler.cpp]
2020-02-26 Forgot to turn off the green led
2020-02-27 Some fixups
    * Fixed a bug which would cause sending result data to never work
    * Added a flow rate enable option in the config to disable the flow rate calcs if a device isn't present
    [configuration.h]
2020-02-28 Fixes and updates to work correctly
    [dissolvedoxygen.cpp, main.cpp, potentialhydrogen.cpp]
2020-02-28 Got it working
    * Fixed timing by testing iTimer offsets on the RPi
    * Fixed issues with iterators in main
    [main.cpp]
2020-02-28 Fixing a bug where the warning wouldn't clear correctly
    [errorhandler.cpp]
2020-03-10 Issue #4: Beginning of the changes to support paho
    * Implement the new client callback handlers
    * Migrate from mosquitto to paho publish (some, not all)
    * Migrate errors to use paho now
    * Updates to the build system to support new MQTT
    [configuration.h]
2020-03-11 Issue #4: Build fixes, should build now for testing
    [main.cpp]
2020-03-12 Issue #4: Fixing a build issue
    [main.cpp]
2020-03-13 Issue #3: Got initial work on being able to store probe names
    * Added configuration functionality
    * Added messaging
    * Cleaned up some naming and variables in configuration
    [configuration.h]
2020-03-13 Issue #3: Do the temp device array more correctly now
    [configuration.h]
2020-03-15 Making sure we can create the config entry if it doesn't exist
    [configuration.cpp]
2020-03-15 Fixing some issues with config parsing
    [configuration.cpp]
2020-03-15 Mostly working now
    * Can add to array
    * Can add a new array
    * Can change array element values by key
    * Still a problem with adding a new array entry if an array already exists
    [configuration.h]
2020-03-15 Adding a TODO to help me remember to fix this
    [configuration.cpp]
2020-03-15 Allow for creating new entries if new temp devices found
2020-03-15 Fixing a function name bug
    [configuration.cpp, main.cpp]
2020-03-15 Fix a bug in reporting available temp devices
    [main.cpp]
2020-03-15 Add some incoming message debug and fix up the temp probe reporting a bit
    [main.cpp]
2020-03-17 Finally got it
    * Can update a temp device using MQTT
2020-03-17 Make it possible to read device name
2020-03-22 Added PAHO non SSL Adafruit IO connection
    * Untested, but should work
    * Not wired up to send data to AIO yet.
    [configuration.h]
2020-03-26 Lots of work to get AIO connections going
    * Added support for secure and insecure
    * Fixed up how we start our MQTT connections
    * Fixed some bugs in the configuration itself
    [configuration.h]
2020-03-27 Fixing bug in MQTT work
    * If you don't create the callback in a way that lives outside the function, this fails pretty badly
    [configuration.h]
2020-03-27 Fixups for more scoping issues
    * Make the connection options a class member, same as the SSL options
    [configuration.h]
2020-03-27 Issue #7: Complete AIO compatibility
    [configuration.cpp]
2020-03-27 Issue #11: Fixing the naming problem in MQTT
    [main.cpp]
2020-03-27 Issue #11: Fixed probe naming
    * Cleaned up the MQTT messages
    * Switched to using the correct field for names
    * Fixed the Temp code to name the probe correctly
    [configuration.cpp, main.cpp]
2020-03-27 Removed a lot of old dead code
    * Removed all references to gpio interrupt, and replaced with wiringPi
    * Cleaned up and removed the flow rate stuff, will revisit in the future
    * Added a common functions file
    [configuration.h]
2020-03-28 Fixing a conflict with wiringPi
    * Turns out wiringPi defines both LOW and HIGH, so I had to rename mine even though it's in a namespace
    [dissolvedoxygen.cpp, main.cpp, potentialhydrogen.cpp]
2020-04-21 Working backwards to get this building again
    [configuration.h]
2020-04-21 Cleanups for Issue #13
    [configuration.h]
2020-04-22 Issue #15: Adding the ability to get rapid water level measurements
    * Make it so the timer can be managed anywhere
    * Add new MQTT messaging to turn on and off fast waterlevel messages
    [main.cpp]
2020-04-22 Issue #16: Add ability to turn off LEDs
    * Set LEDS off via the Atlas API
    [atlasscientifici2c.h, dissolvedoxygen.cpp, main.cpp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]
2020-08-31 More fixes and updates
    * Beginnings of a time remaining in millis for timers
    * Fixed some build issues where I clobbered CXX_FLAGS accidentally
2020-08-31 More work on errors
    * Fixup ErrorHandler to be a bit more flexible
    * Added some errors into main
    * Added some more doxygen documentation
    [errorhandler.cpp, main.cpp]
2020-09-03 More work getting this going
    * More error handling fixuups
    * Improve the MQTT callbacks I think. This should make them less complicated.
    * Remove the old MQTT directory, we aren't using it anymore.
    * Working main, still have an error in the timers I think.
    [configuration.h]
2020-09-05 Too many changes to document well
    * Switched from mqtt::message_ptr to just putting the message into the publish(), this may have created a memory leak though
    * Fixed up a lot of printing issues
    * Lots of cmake changes for debug additions
    [configuration.cpp, dissolvedoxygen.cpp, main.cpp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]
2020-09-06 Fixing missing header file
    [main.cpp]
2020-09-06 Printing fixups, and a small change to how I store the callbacks for the MQTT setup
    [configuration.h]
2020-09-09 Updating the board to the latest
    [aquarium.brd, aquarium.sch]
2020-09-09 Fixups and new functions
    * Added monitoring for GPIO pins, this is a read only right now, will need to add type later
    * Fixed some prints
    * Take out the spi device, this is handled internally by wiringPi
    [configuration.h]
2020-09-13 A quick update
    * If the overflow sensors report high water, make that a warning and send a message

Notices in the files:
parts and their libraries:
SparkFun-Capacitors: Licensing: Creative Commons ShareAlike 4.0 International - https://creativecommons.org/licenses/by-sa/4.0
